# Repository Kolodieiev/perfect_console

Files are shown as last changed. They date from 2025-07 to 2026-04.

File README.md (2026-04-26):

Проєкт “Ідеальна консоль” це спроба створити універсальну електронну плату, для комфортного програмування на її основі різноманітних електронних пристроїв, таких як ігрові консолі, програвачі музики, пульти керування тощо.
Завдяки продуктивному мікроконтролеру ESP32S3 N16R8 плата може виконувати купу завдань та обчислень, а наявність 8 мб оперативної та 16 мб постійної пам'яті, забезпечує достатньо місця для реалізації досить об’ємних проєктів прошивок, в тому числі з використанням графіки. 

<br>

#### Прошивка
В репозиторії, крім файлів проєкту електронної плати, містяться повністю відкриті базові прошивки, написані мовою C++, для обох мікроконтролерів. Прошивка для ESP32S3 базується на основі фреймворку Pixeler, та містить багато прикладів побудови графічного інтерфейсу різної складності. 
До їх списку входять різні види меню, графічний інтерфейс для сканування та підключення до WiFi точки доступу, файловий менеджер, mp3-плеєр, вікна з різними видами налаштувань, приклади 2D-ігор на кастомному ігровому рушії та інші.

Скриншоти з прошивки:<br>
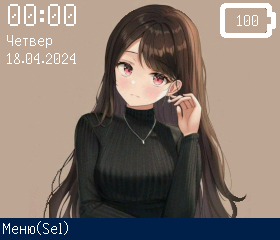
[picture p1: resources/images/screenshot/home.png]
main_context

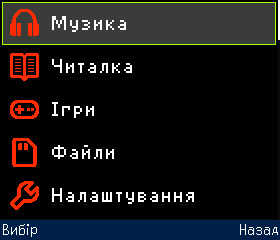
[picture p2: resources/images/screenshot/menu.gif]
menu_context
<br>
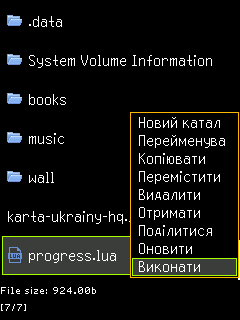
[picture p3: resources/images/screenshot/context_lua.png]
file_manager

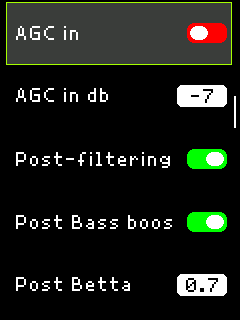
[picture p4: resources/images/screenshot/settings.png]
settings_context

<br>
Демонстрація можливостей ігрового рушія(зібрано в портованій версії для ПК):
<br>
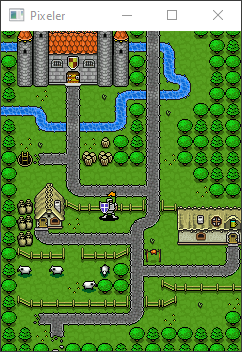
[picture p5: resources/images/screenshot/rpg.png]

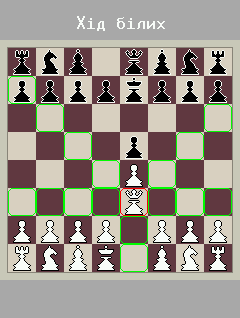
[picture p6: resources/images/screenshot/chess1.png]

<br>
Більше скриншотів можна знайти в [Screenshots](resources/images/screenshot)
<br>

#### Для кого
Проєкт розрахований на користувачів, які хочуть навчитися виготовляти або замовляти виготовлення електронних плат, збирати їх по схемі та програмувати мікроконтролери. Також він підійде досвідченим розробникам, яким просто цікаво програмувати залізо у вільний час та вивчати щось нове для себе. 
Для збірки проєкту необхідно мати досвід пайки середнього або вище рівня та відповідні інструменти.

<br>

#### Модульність
Головна особливість плати полягає в тому, що користувач може самостійно обрати, який модуль йому використовувати для своїх задач. На платі передбачено місця тільки для основних компонентів, або таких, які складно закріпити в корпусі окремо, все інше необхідно самостійно обирати з огляду на власні потреби та можливості.
<br>
<br>
[Фото зібраних плат](resources/images/pcb)

<br>

#### Корпус
Розробка корпусу для виготовлення на 3D-принтері не планується в межах даного проєкту. Користувач повинен самостійно спроектувати корпус для свого пристрою в залежності від використаних модулів. 

<br>

#### Мікроконтролер
Для забезпечення функціонування плати використовується два мікроконтролера - далі МК, ESP32S3 та CH32V006E8R6. Ці МК обрано через дуже хороше співвідношення ціна/можливості та значну кількість GPIO. Очікується, що перший МК буде мозком пристрою, який виконуватиме основну прошивку, а другий - допоміжний, що виконуватиме роль мікросхеми розширення, завдяки якій вивільняються 11 пінів основного МК. Мікроконтролери можуть спілкуватися один з одним по шині I2C. Для підтримки рівноправного двостороннього зв'язку додано окрему лінію між МК, яка може бути використана для генерації переривань.

<br>

#### GPIO
До однієї з двох шин SPI на ESP32 приєднано роз’єм карти пам’яті MicroSD. Усі інші незадіяні виводи цього МК виведено на штирьові роз’єми та контактні площадки. Усього доступно вільних пінів 19 + шина I2C + UART. Усі вільні виводи ESP32 згруповано на штирьових роз’ємах таким чином, щоб до них можна було підключити з допомогою шлейфів будь-який популярний SPI-дисплей, модуль звуку, який керується по I2S протоколу, цифровий мікрофон та UART-версію модулів LoRa. До кожної групи роз’ємів додано піни живлення, які вмикаються польовими транзисторами. В кастомній прошивці до цих роз’ємів можуть бути підключені будь-які інші модулі на розсуд користувача.

Частина виводів(п’ять) CH32 підключені до ключів керування живленням. Усі інші піни також виведені на штирьові роз’єми. У стандартній конфігурації до цих пінів очікується підключення кнопки живлення, кнопки PTT, ліній UART, програматора, та 8 кнопок керування, 6 з яких, можуть бути налаштовані як сенсорні. 

В будь-якій користувацькій конфігурації обов’язковою є тільки кнопка живлення. Усі інші вільні виводи мікроконтролерів можуть бути налаштовані, відповідно до їх документації, на інші задачі. Окрім того, за особливої необхідності, можуть бути звільнені додаткові 4 піна CH32, які підключені до затворів ключів живлення в кожній групі штирьових роз’ємів.

<br>

#### Живлення
Очікується, що плата “Ідеальної консолі” буде використовуватися саме в автономному варіанті з використанням високоємнісного акумулятора або збірки акумуляторів. Проте з деякими незначними модифікаціями можливе її використання виключно в стаціонарному варіанті, наприклад, для навчання або відлагодження. На платі передбачено місця для штирьових роз’ємів, до яких можна підключити будь-який USB роз’єм, та будь-який понижуючий DC-DC перетворювач. Також окремо виведено роз’єм з підсиленими доріжками для живлення зовнішніх пристроїв, як від DC-DC перетворювача, так і напряму від акумулятора. Для заряджання акумулятора використовується модуль TP4056 без захисту. Для нього передбачено окреме місце на платі для відводу тепла. Плату або плати захисту від перерозряду пропонується встановлювати окремо на акумулятор в залежності від того, які значення струму планується знімати з нього. Якщо очікується загальне споживання струму понад 1А, дуже рекомендується припаювання проводів до плати, замість використання штирьових роз’ємів в схемі живлення.

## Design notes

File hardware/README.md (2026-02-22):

##### Загальні рекомендації

* Не запаюйте акумулятор та DC-DC перетворювач безпосередньо до плати, поки не завантажите прошивку на CH32V006E8R6.
* Не приєднуйте жоден із модулів, таких як дисплей, до плати та не вставляйте карту пам'яті в роз'єм, доки не переконаєтесь, що на платі відсутні КЗ, а обидва мікроконтролери успішно прошиті.
* Мікроконтролер CH32V006E8R6 не може бути замінений на будь-яку інший з серії через невідповідність пінів.
* Модуль ESP32-S3 не може бути замінений на звичайний ESP32 чи S2 чи будь-який інший через невідповідність пінів та підтримку можливостей.
* Шлейф дисплею мусить бути якомога коротшим, настільки дозволяють вимоги корпусу. 
* Резистори підтяжки ліній MISO/MOSI/CLK карти пам'яті можуть мати значення 10-22к. 
* Резистори підтяжки затворів мосфетів можуть мати значення 30к-50к.
* Резистори обмеження струму на затвори мосфетів можуть мати значення 10-30ом.
* Конденсатори 10мкф можуть бути замінені на low-esr електролітичні або танталові, але з урахуванням полярності.
* DC-DC перетворювач може бути використаний будь-який на 3.3В 1.5А+. Рекомендованими є XL63070/TPS63070/mini-560 3.3v.
* Захист акумулятора від перерозряду, КЗ та високих струмів необхідно купити окремо з розрахунку 1 модуль на 2А потенційного струму.
* Якщо планується використання підсилювача звуку або модуля LoRa, рекомендуються купувати високострумний акумулятор та з'єднати паралельно два модуля захисту.
* Під модуль TP4056 рекомендується розмістити термопрокладку для відводу тепла на плату.
* Для комфортного використання плати рекомендується купувати акумулятор з ємністю від 1000маг. Бажано 2-3к, якщо планується використання WiFi. Найкраще для цієї задачі підходять високострумні 18650 або 21700 зі встановленими самостійно модулями захисту.
* Під модуль ESP32-S3 бажано нанести маленьку каплю процесорної термопасти і міцно притиснути модуль до плати, якщо паста густа, можна легко порухати модуль в різні сторони, для кращого розмазування термопасти. 
* Запаювати площадку знизу не обов'язково і не рекомендуються новачкам.
* Дисплей може бути використаний будь-який SPI, але основна прошивка буде розроблюватися тільки для дисплеїв на драйвері ST7789.
* Модуль мікрофона, якщо планується його використання, може бути замінений на будь-який інший сумісний з INMP441.
* Модуль LoRa може бути використаний серії E32 або E220 з UART на 400-440мГц. Інші не тестувались та не мають бібліотек підтримки. 
* Усі модулі не є обов'язковими для функціонування плати, окрім модулів живлення, мікроконтролерів та їх обв'язки.

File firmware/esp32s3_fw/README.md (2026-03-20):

> [!WARNING]
> Прошивка збирається плагіном `Pioarduino` та не може бути зібрана за допомогою `Platformio`!

##### Інструкція з прошивки ESP32S3

* Перш ніж розпочинати прошивку ESP32S3, необхідно спершу прошити CH32V006E8R6. Без цього пункту нічого не вийде.
* Коли CH32 прошито, потрібно обов'язково підключити акумулятор та понижуючий DC-DC перетворювач на свої місця. Звіряйтесь зі схемою куди, що і якою сторною підключаєте, аби не пошкодити плату чи компоненти на ній.
* Коли акумулятор підключено, на контактах 4v2 та GND(поряд з 4v2) роз'єму PWR_OUT повинна бути напруга акумулятора. Якщо напруга відсутня, а на акумуляторі встановлено плату захисту, спробуйте підключити короткочасно плату консолі до зарядного пристрою. Після цього плата захисту повинна розблокуватися, а на вищезгаданих контактах з'явиться напруга.
Якщо цього не відбулося, знайдіть та приберіть КЗ на платі консолі та переконайтеся в якості пайки.
* Якщо напруга акумулятора наявна на платі консолі, натисніть та міцно утримуйте протягом 4 сек кнопку, яка підключена до контактів PWR_Btn, або замкніть на 4 сек ці контакти металевим пінцетом. 
* Заміряйте напругу на контактах 4V2 та нижньому GND, вона не повинна зникнути. А на контактах 3v3 та верхньому GND має з'явитися напруга 3.3В з DC-DC перетворювача.
Якщо напруга акумулятора зникла, шукайте КЗ на платі. Якщо напруга з DC-DC перетворювача не з'явилася, заміряйте напругу на затворі одного з транзисторів Q5/Q6 відносно нижнього GND на роз'ємі PWR_OUT. Там повинна бути напруга акумулятора. Якщо напруга відсутня, шукайте проблему в якості пайки CH32 або по шляху доріжки від транзистора до CH32. Краще всього для цього використовувати файли проєкту плати для Kicad.
* Якщо відповідні напруги наявні на контактах PWR_OUT. Підключіть плату консолі до ПК. Якщо драйвери встановлено коректно, у списку пристроїв повинен з'явитися USB JTAG/serial debug unit. Якщо пристрій автоматично підключається і відключається, натисніть кнопку Boot на платі консолі і не відпускаючи її короткочасно натисніть Reset на платі. Після цього можна відпустити Boot. Пристрій USB JTAG/serial debug unit повинен перестати автоматично перепідключатися.
* Відкрийте VS Code, встановіть до нього плагін Pioarduino. Зверніть увагу, плагін повинен називатися саме Pioarduino, а не Platformio. Другий плагін необхідно видалити та видалити папку .platformio, якщо його було встановлено раніше.
* Відкрийте папку проєкта таким чином, щоб цей файл README знаходився на найвищому рівні в списку проєкта. У Windows можна клікнути на порожнє місце поряд з цим файлом у файловому менеджері, та обрати пункт відкрити в VS Code. 
* Зберіть прошивку та завантажте її на МК через інтерфейс або кнопки на панелі навігації плагіна. Більш детальну інструкцію зі збірки проєкта можна знайти в мережі, якщо виникнуть додаткові питання.
* Якщо все пройшло успішно, можна підключати модулі дисплея, звукової карти тощо.

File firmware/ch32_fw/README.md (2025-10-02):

Прошивка допоміжного мікроконтролера CH32V006E8R6 в корпусі QSOP-24 для проєкту "Ідеальна консоль". 
Прошивка збирається в програмі MounRiver Studio 2 та заливається на МК з допомогою універсального, для мікроконтролерів WCH, програматора WCH-LinkE V2.
Важливо, програматор WCH-Link V1 не підходить для програмування CH32V006E8R6!

##### Підключення програматора

* Коли плату зібрано, необхідно від'єднати USB-живлення, акумулятор та, можливо, вхід DC-DC перетворювача. 
* Після цього потрібно підключити програматор до плати за наступною схемою:

5V програматора -> 4v2 на роз'ємі PWR_OUT.
GND програматора -> GND на роз'ємі PWR_OUT.
SWDIO програматора -> SWIO на роз'ємі CH_FLASH.
SWCLK програматора -> CH_RESET на роз'ємі CH_FLASH.

##### Налаштування проєкту

* Далі необхідно підключити програматор до ПК, на якому встановлено "MounRiver Studio 2".
* Після підключення програматора, в "MounRiver Studio 2" потрібно відкрити цей проєкт прошивки та перейти в меню "Flash -> Download Configuration".
* В розділі "General -> Target MCU Type" обрати "CH32V006 -> CH32V006E8R6".
* В розділі "Download -> Download Settings" натиснути кнопку "Query" навпроти поля "Debugger Target Mode". 
Повинне з'явитися повідомлення "Succeed", а в полі встановитися автоматично вибір "RISC-V". Якщо з'явилося повідомлення "WCH-Link not found" перевірте підключення програматора до ПК та наявність драйверів. На Windows драйвер встановлюється разом з "MounRiver Studio 2" автоматично. Якщо в полі вибору встановився "ARM", необхідно змінити режим на програматорі, як вказано в інструкції до нього.
* Далі в полі "Erase Code Flash" вручну обрати пункт "By Power Off" та натиснути "Applay" навпроти цього поля. Повинно з'явитися повідомлення "Clear CodeFlash... Succeed".
* Тепер, якщо натиснути кнопку "Query" навпроти поля "Linked MCU Type", в полі автоматично повинне встановитися значення "CH32V002/3/4/5/6/7".
* Після цього необхідно натиснути головну кнопку "Applay" вікна, для збереження налаштувань.

##### Збірка проєкту та прошивка мікроконтролера

* Після того, як закрилося вікно налаштувань, натисніть кнопку "Build Project".
* Після збірки проєкту натисніть кнопку "Download". У виводі повинні з'явитися повідомлення з етапами прошивки, останнє із яких - "Download Finished". Якщо отримано будь-яке інше повідомлення про помилку, переконайтеся у якості підключення програматора до плати, а також у якості пайки штирьових розємів та самого CH32V006E8R6.
* Тепер CH32V006E8R6 прошитий і готовий до використання. Від'єднайте програматор від плати після чого підключіть акумулятор та DC-DC.
* Після цього можна перейти до прошивки ESP32S3.

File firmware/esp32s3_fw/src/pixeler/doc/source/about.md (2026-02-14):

# Про проєкт

Pixeler це компроміс між зручним для використання, швидким та надійним кодом. Проте на першому місці все ж таки стоять зручність та швидкодія.

Для кращого розуміння, принципів функціонування фреймоврку варто ознайомитися з наступними підходами до його розробки:
* Ми дуже не любимо послідовності викликів C-шних функцій, тому загортаємо все в зручні класи.
Окрім коду де потрібна максимальна продуктивність. В таких випадках можна й регістр читати.
* Замість копіювання даних або об'єктів, ми користуємося сирими вказівниками та посиланнями, окрім випадків коли потрібна саме копія.
* Ми завжди хочемо перевикористовувати великі масиви даних, такі як зображення. Тому об'єкт не видаляє дані за отриманим вказівником, якщо ці дані потенційно займають багато місця в пам'яті та можуть бути перевикористані іншим об'єктом.
* В той же час ми не хочемо кешувати вказівники на всі створені невеликі об'єкти. Тому якщо об'єкт, що приймає вказівник, є контейнером для цих вказівників, він повинен самостійно викликати видалення за цими вказівниками, навіть, якщо не він їх створював.
* Ми не бачимо нічого поганого в тому, щоб отримувати доступ до "популярного" об'єкта по закешованому вказівнику, навіть, якщо цей об'єкт видаляється в іншому місці. Але лише за умови, що використовується машина станів, яка гарантовано унеможливить звертання до висячого вказівника.
* Виклик віртуальних методів кращий за шаблони.
* Якщо отримали помилку або неочікуване значення в коді, викликаємо перевантаження прошивки, аби розробник звернув увагу на цю проблему під час тестування.
Але це не стосується обробки зовнішніх вхідних даних.
* За бажання, необережними програмуванням можна зламати майже будь-яку систему. 
Тому перевіряємо тільки зовнішні вхідні дані, вказівники на nullptr та значення, які програміст вводить дуже часто через що може випадково помилитися.
В інших випадках очікуємо, що дані валідні, аби не роздувати прошивку перевірками заради перевірок. Тому якщо, наприклад, метод повинен отримувати ціле число в позитивному діапазоні, параметр методу краще оголосити беззнаковим, а відповідальність за вхідне значення перекласти на розробника, аніж додавати перевірку знака, яка можливо ніколи і не знадобиться.

Не дивлячись на те, що майже всі ці підходи порушують загальноприйняті принципи класичного програмування, їх було обрано з певних, цілком об'єктвиних для програмування мікроконтролерів, причин.<br>
Ви можете лише прийняти їх або відмовитися від використання Pixeler, якщо вважаєте такий підхід до програмування недостатньо надійним для вашої задачі.

Розробка проєкту виконується на ОС Linux та періодично тестується на Windows, тому деякі інструменти збірки можуть бути налаштовані некоректно на інших системах окрім Linux в певний момент.<br>
Для тестування прошивки використовується мікроконтролер ESP32S3, на ESP32 та ESP32P4 код тестується періодично, 
тому деякий функціонал може працювати некоректно в певний момент. Або може працювати дещо інакше, через внутрішні відмінності цих мікроконтролерів.

## Про документацію

Ця документація створена з метою навчити створювати прошивки для ESP на Pixeler будь-кого, в тому числі новачків.
Вона не містить повного переліку та опису усіх методів в класах. З ним користувач повинен самостійно ознайомитись у відповідних файлах.
Усі неочевидні моменти архітектури Pixeler, будуть описані в ній. Проте користувач повинен самостійно розібратися з усіма, незрозумілими для нього, речами в мовах C++/Lua за допомогою ШІ або пошукових систем.

## Скорочення та визначення

МК - Мікроконтролер.<br>
ESP - Мікроконтролер серії ESP32/ESP32S3/ESP32P4.
GUI - Графічний інтерфейс користувача.

## Правила іменування

В Pixeler використовуються наступні правила іменування.

* Префікс `I` в імені типу означає, що клас є абстрактним. Наприклад, `IWidget`.
* Префікс `__`(два нижніх підкреслення) в імені методу означає, що метод не рекомендується або заборонено до виклику користувачем. Наприклад, `void __tick();`
* Префікс `_`(одне нижнє підкреслення) в імені об'єкта означає, що він є глобальним. Наприклад, `_fs`.
* Усі букви в верхньому регістрі означають ім'я визначення або константного значення. Наприклад, `SOME_NAME`.
* Для іменування типів використовується `UpperCamelCase`.
* Для іменування методів використовується `lowerCamelCase`.
* Для іменування об'єктів використовується `snake_case`.

## Повідомити про помилку

<a href="https://github.com/Kolodieiev/perfect_console/issues/new" target="_blank">Створити issue на Github</a>

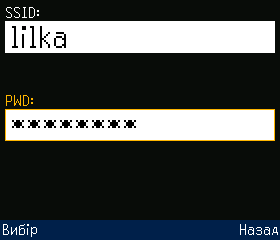
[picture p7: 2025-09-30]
resources/images/screenshot/textbox.png

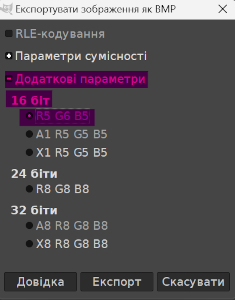
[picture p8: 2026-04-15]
firmware/esp32s3_fw/src/pixeler/doc/source/img/img_convert/gimp_bmp_convert.png

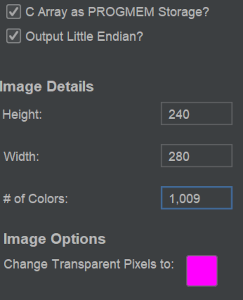
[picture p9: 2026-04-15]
firmware/esp32s3_fw/src/pixeler/doc/source/img/img_convert/GUIslice_Image2C.png

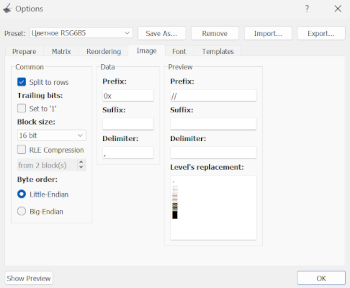
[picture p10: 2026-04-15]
firmware/esp32s3_fw/src/pixeler/doc/source/img/img_convert/LCD_img_converter_2.png

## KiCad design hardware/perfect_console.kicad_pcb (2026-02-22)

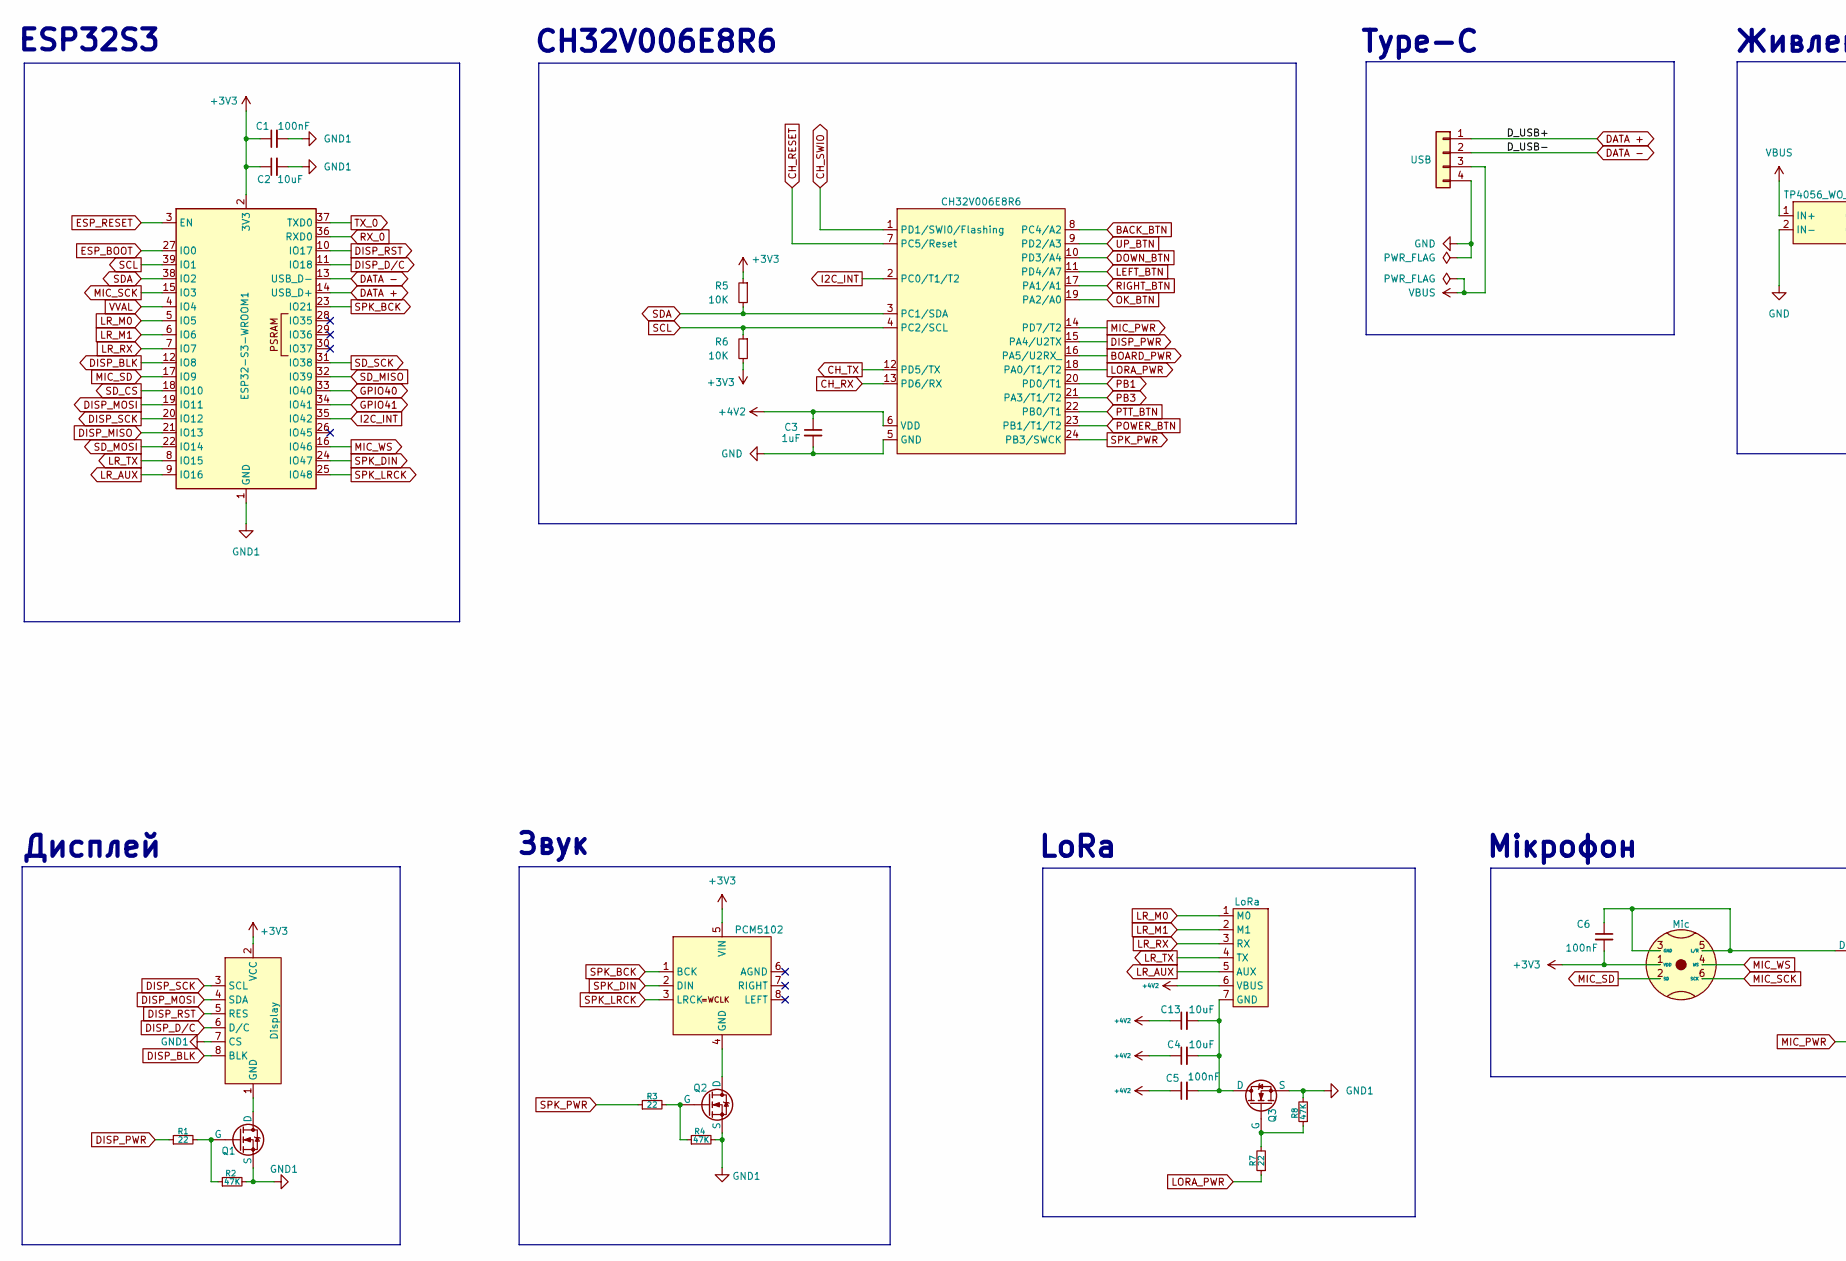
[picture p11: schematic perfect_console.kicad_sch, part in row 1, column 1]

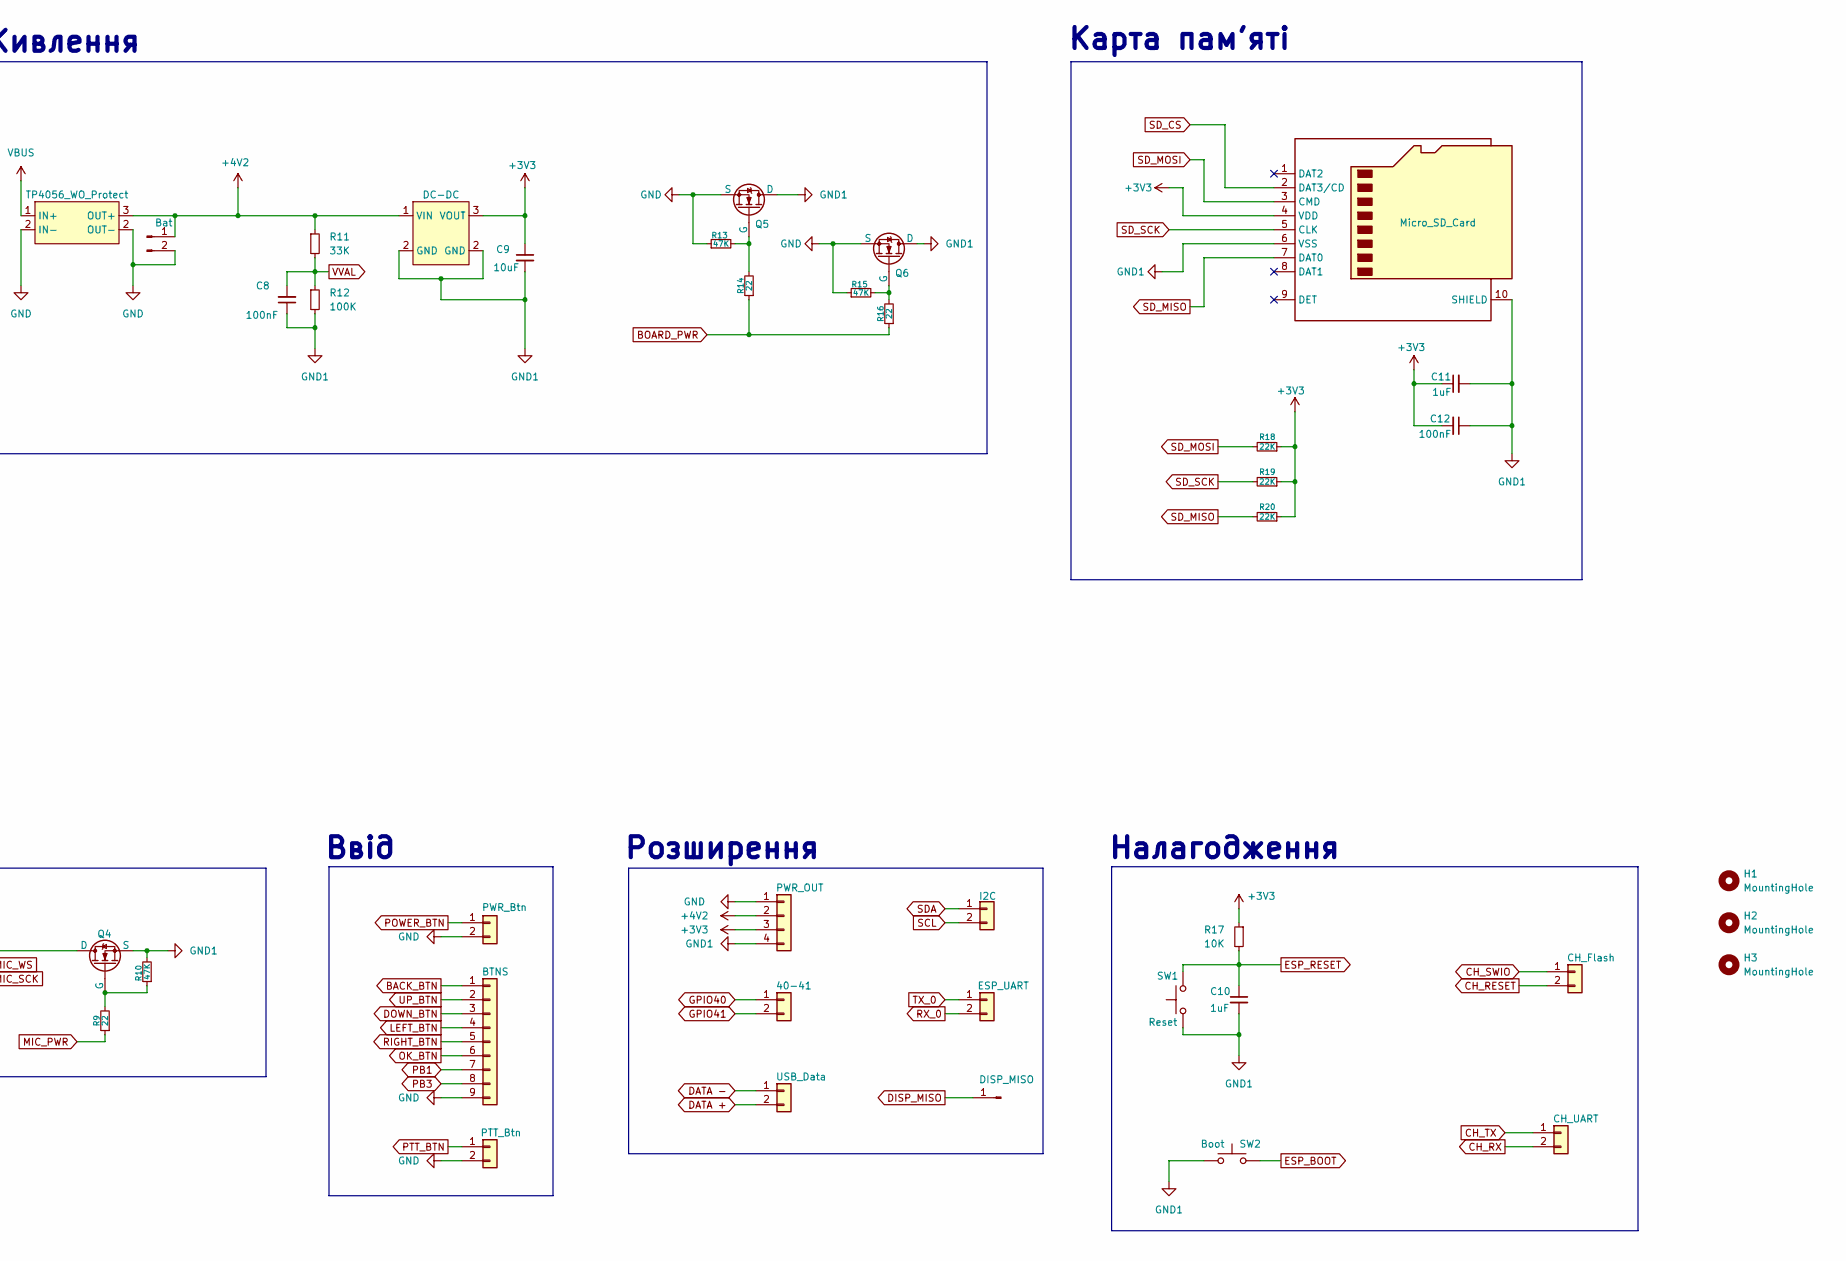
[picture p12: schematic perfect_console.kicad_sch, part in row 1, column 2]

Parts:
C1, C5, C6, C8, C12: 100nF; C_1206_3216Metric_Pad1.33x1.80mm_HandSolder
C2, C4, C9, C13: 10uF; C_1206_3216Metric_Pad1.33x1.80mm_HandSolder
C3, C10, C11: 1uF; C_1206_3216Metric_Pad1.33x1.80mm_HandSolder
H1, H2, H3: MountingHole; MountingHole_2.7mm_M2.5_DIN965_Pad
J1: USB; PinHeader_1x04_P2.54mm_Vertical
J2: TP4056_WO_Protect; Charge_Controller_TP4056_WO_Protect
J3: Bat; PinHeader_1x02_P2.54mm_Vertical
J4: PWR_Btn; PinHeader_1x02_P2.54mm_Vertical
J5: BTNS; PinHeader_1x09_P2.54mm_Vertical
J6: PTT_Btn; PinHeader_1x02_P2.54mm_Vertical
J7: PWR_OUT; PinHeader_1x04_P2.54mm_Vertical
J8: 40-41; PinHeader_1x02_P2.54mm_Vertical
J9: USB_Data; PinHeader_1x02_P2.54mm_Vertical
J10: I2C; PinHeader_1x02_P2.54mm_Vertical
J11: ESP_UART; PinHeader_1x02_P2.54mm_Vertical
J12: CH_UART; PinHeader_1x02_P2.54mm_Vertical
J13: CH_Flash; PinHeader_1x02_P2.54mm_Vertical
J14: Micro_SD_Card; J_SD_Card-micro_socket_A
J16: DISP_MISO; TestPoint_Pad_1.5x1.5mm
Q1, Q2, Q3, Q4, Q5, Q6: A09T; SOT-23
R1, R3, R7, R9, R14, R16: 22; R_1206_3216Metric_Pad1.30x1.75mm_HandSolder
R2, R4, R8, R10, R13, R15: 47K; R_1206_3216Metric_Pad1.30x1.75mm_HandSolder
R5, R6, R17: 10K; R_1206_3216Metric_Pad1.30x1.75mm_HandSolder
R11: 33K; R_1206_3216Metric_Pad1.30x1.75mm_HandSolder
R12: 100K; R_1206_3216Metric_Pad1.30x1.75mm_HandSolder
R18, R19, R20: 22K; R_1206_3216Metric_Pad1.30x1.75mm_HandSolder
SW1: Reset; SW_PUSH_6mm
SW2: Boot; SW_PUSH_6mm
U1: ESP32-S3-WROOM1; ESP32-S3-WROOM-1
U2: Display; PinHeader_1x08_P2.54mm_Vertical
U3: PCM5102; PinHeader_1x05_P2.54mm_Vertical
U4: CH32V006E8R6; Allegro_QSOP-24_3.9x8.7mm_P0.635mm
U5: LoRa; PinHeader_1x07_P2.54mm_Vertical
U7: Mic; PinHeader_2x03_P2.54mm_Vertical
U8: DC-DC; PinHeader_2x02_P2.54mm_Vertical

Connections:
+3V3: C1.1, C2.1, C6.2, C9.1, C11.1, C12.2, J7.3, J14.4 (VDD), R5.1, R6.2, R17.1, R18.1, R19.1, R20.1, U1.2 (3V3), U2.2 (VCC), U3.5 (VIN), U7.1 (VDD), U8.3 (VOUT)
+4V2: C3.1, C4.1, C5.1, C13.1, J2.3 (OUT+), J3.1, J7.2, R11.1, U4.6 (VDD), U5.6 (VBUS), U8.1 (VIN)
BACK_BTN: J5.1, U4.8 (PC4/A2)
BOARD_PWR: R14.1, R16.1, U4.16 (PA5/U2RX_)
CH_RESET: J13.2, U4.7 (PC5/Reset)
CH_RX: J12.2, U4.13 (PD6/RX)
CH_SWIO: J13.1, U4.1 (PD1/SWI0/Flashing)
CH_TX: J12.1, U4.12 (PD5/TX)
DATA +: J1.1, J9.2, U1.14 (USB_D+)
DATA -: J1.2, J9.1, U1.13 (USB_D-)
DISP_BLK: U1.12 (IO8), U2.8 (BLK)
DISP_D/C: U1.11 (IO18), U2.6 (D/C)
DISP_MISO: J16.1, U1.21 (IO13)
DISP_MOSI: U1.19 (IO11), U2.4 (SDA)
DISP_PWR: R1.1, U4.15 (PA4/U2TX)
DISP_RST: U1.10 (IO17), U2.5 (RES)
DISP_SCK: U1.20 (IO12), U2.3 (SCL)
DOWN_BTN: J5.3, U4.10 (PD3/A4)
ESP_BOOT: SW2.2, U1.27 (IO0)
ESP_RESET: C10.1, R17.2, SW1.2, U1.3 (EN)
GND: C3.2, J1.4, J2.2 (IN-), J3.2, J4.2, J5.9, J6.2, J7.1, Q5.2 (S), Q6.2 (S), R13.1, R15.1, U4.5 (GND)
GND1: C1.2, C2.2, C8.1, C9.2, C10.2, C11.2, C12.1, J7.4, J14.6 (VSS), J14.10 (SHIELD), Q1.2 (S), Q2.2 (S), Q3.2 (S), Q4.2 (S), Q5.3 (D), Q6.3 (D), R2.2, R4.2, R8.2, R10.2, R12.2, SW1.1, SW2.1, U1.1 (GND), U1.40 (GND), U1.41 (GND), U2.7 (CS), U8.2 (GND)
GPIO40: J8.1, U1.33 (IO40)
GPIO41: J8.2, U1.34 (IO41)
I2C_INT: U1.35 (IO42), U4.2 (PC0/T1/T2)
LEFT_BTN: J5.4, U4.11 (PD4/A7)
LORA_PWR: R7.1, U4.18 (PA0/T1/T2)
LR_AUX: U1.9 (IO16), U5.5 (AUX)
LR_M0: U1.5 (IO5), U5.1 (M0)
LR_M1: U1.6 (IO6), U5.2 (M1)
LR_RX: U1.7 (IO7), U5.3 (RX)
LR_TX: U1.8 (IO15), U5.4 (TX)
MIC_PWR: R9.1, U4.14 (PD7/T2)
MIC_SCK: U1.15 (IO3), U7.6 (SCK)
MIC_SD: U1.17 (IO9), U7.2 (SD)
MIC_WS: U1.16 (IO46), U7.4 (WS)
unnamed: Q1.3 (D), U2.1 (GND)
unnamed: Q1.1 (G), R1.2, R2.1
unnamed: Q2.3 (D), U3.4 (GND)
unnamed: Q2.1 (G), R3.2, R4.1
unnamed: C4.2, C5.2, C13.2, Q3.3 (D), U5.7 (GND)
unnamed: Q3.1 (G), R7.2, R8.1
unnamed: C6.1, Q4.3 (D), U7.3 (GND), U7.5 (L/R)
unnamed: Q4.1 (G), R9.2, R10.1
unnamed: Q5.1 (G), R13.2, R14.2
unnamed: Q6.1 (G), R15.2, R16.2
OK_BTN: J5.6, U4.19 (PA2/A0)
PB1: J5.7, U4.20 (PD0/T1)
PB3: J5.8, U4.21 (PA3/T1/T2)
POWER_BTN: J4.1, U4.23 (PB1/T1/T2)
PTT_BTN: J6.1, U4.22 (PB0/T1)
RIGHT_BTN: J5.5, U4.17 (PA1/A1)
RX_0: J11.2, U1.36 (RXD0)
SCL: J10.2, R6.1, U1.39 (IO1), U4.4 (PC2/SCL)
SDA: J10.1, R5.2, U1.38 (IO2), U4.3 (PC1/SDA)
SD_CS: J14.2 (DAT3/CD), U1.18 (IO10)
SD_MISO: J14.7 (DAT0), R20.2, U1.32 (IO39)
SD_MOSI: J14.3 (CMD), R18.2, U1.22 (IO14)
SD_SCK: J14.5 (CLK), R19.2, U1.31 (IO38)
SPK_BCK: U1.23 (IO21), U3.1 (BCK)
SPK_DIN: U1.24 (IO47), U3.2 (DIN)
SPK_LRCK: U1.25 (IO48), U3.3 (LRCK)
SPK_PWR: R3.1, U4.24 (PB3/SWCK)
TX_0: J11.1, U1.37 (TXD0)
UP_BTN: J5.2, U4.9 (PD2/A3)
VBUS: J1.3, J2.1 (IN+)
VVAL: C8.2, R11.2, R12.1, U1.4 (IO4)

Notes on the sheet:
Розширення
Карта пам'яті
Налагодження
Дисплей
CH32V006E8R6
Живлення
Звук
Type-C
ESP32S3
Ввід
LoRa
Мікрофон

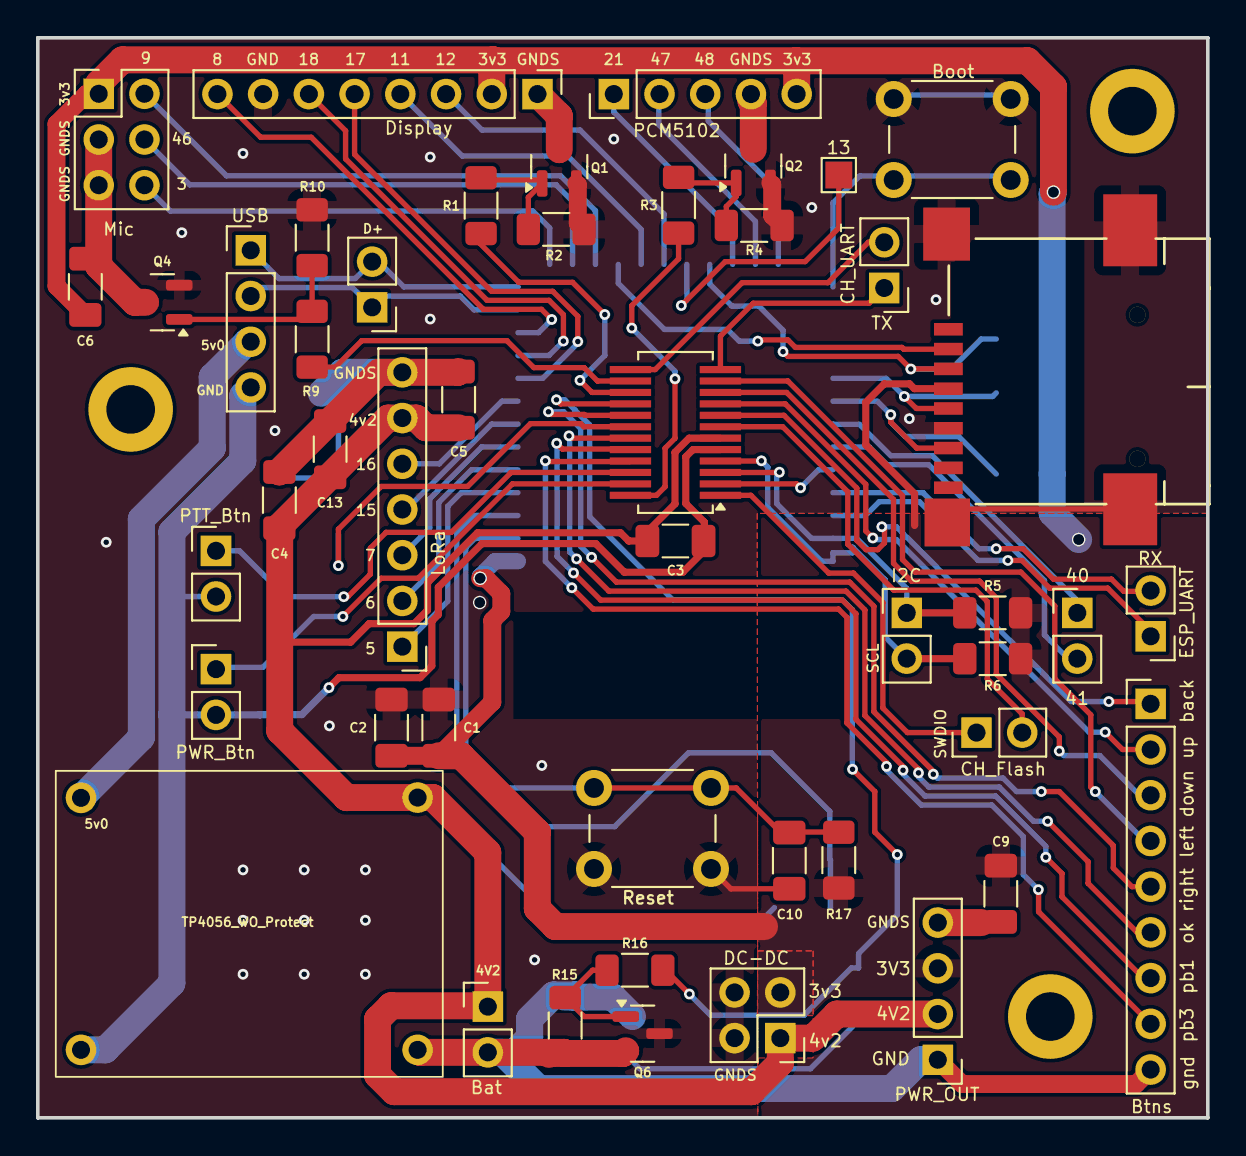
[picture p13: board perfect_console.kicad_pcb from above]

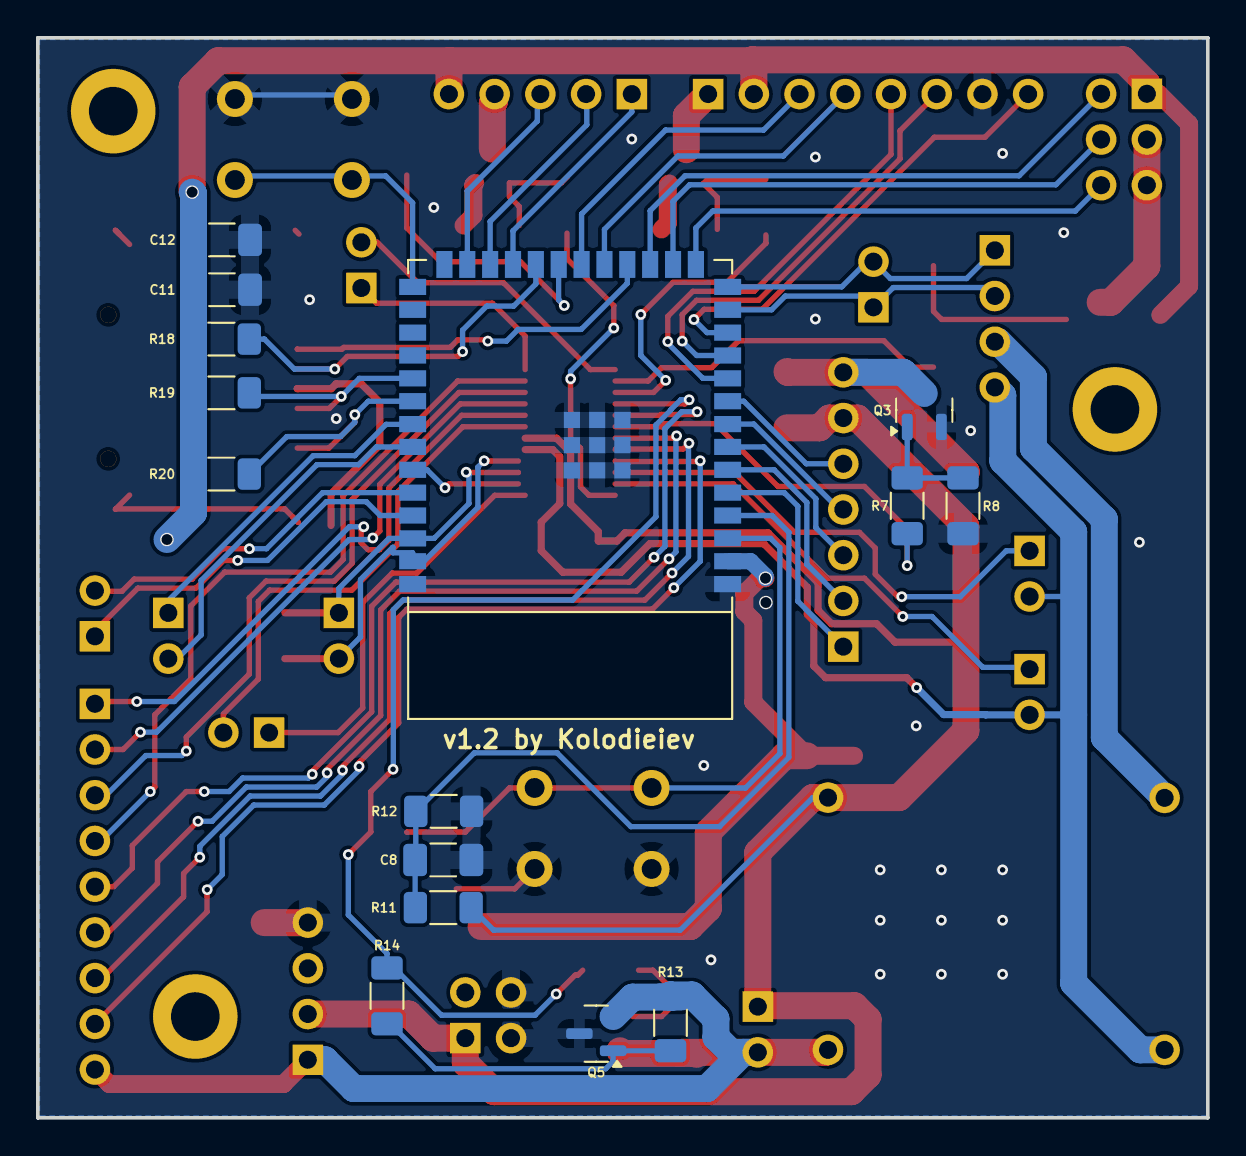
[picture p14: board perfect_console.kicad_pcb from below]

Board: 2 copper layers, 65.0 x 60.0 mm, 65 parts (15 on the bottom side), 67 nets.

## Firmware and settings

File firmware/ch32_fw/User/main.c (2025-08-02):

#include <debug.h>
#include <gpio.h>
#include <i2c_slave.h>
#include "input.h"
#include "touch.h"
#include "CoprocessorCMD.h"

// #define DEBUG_LOG

//------------------------------------------------------------------------------------------------------------- btns
#define BTNS_NUM 7

#define PIN_POWER_BTN 23

#define PIN_PTT_BTN 22
#define PIN_OK_BTN 19
#define PIN_BACK_BTN 8
#define PIN_LEFT_BTN 11
#define PIN_RIGHT_BTN 17
#define PIN_UP_BTN 9
#define PIN_DOWN_BTN 10

#define PIN_PB1 20
#define PIN_PB3 21

#define INPUT_UPD_TIME_MS 10

//------------------------------------------------------------------------------------------------------------- keys
#define PIN_MIC_KEY 14
#define PIN_DISPLAY_KEY 15
#define PIN_POWER_KEY 16
#define PIN_LORA_KEY 18
#define PIN_AUDIO_OUT_KEY 24

#define PIN_I2C_INT 2

//------------------------------------------------------------------------------------------------------------- i2c

#define BTNS_NUM_BUFF_SIZE ((BTNS_NUM + 7) / 8)
#define I2C_TEMP_BUFF_SIZE 5

#define I2C_FREQ 100000
#define RX_ADDR 0x66

//

volatile uint8_t _data_size_to_send = 0;
uint8_t _i2c_out_buff[I2C_TEMP_BUFF_SIZE] = {0};
uint8_t _btns_state_buff[BTNS_NUM_BUFF_SIZE] = {0};

//------------------------------------------------------------------------------------------------------------- power
#define TIME_TO_TOGGLE_PWR 3000
uint8_t _is_sleeping = 0;

//------------------------------------------------------------------------------------------------------------- func
void initPins (void);
void deinitPins (void);

void initPwrBtnExti (void);
void deinitPwrBtnExti (void);

void goToSleep (void);
void wakeUp (void);
void EXTI7_0_IRQHandler (void) __attribute__ ((interrupt ("WCH-Interrupt-fast")));

void i2c_read_handler (const uint8_t *in_buff, uint8_t in_buff_size);
void i2c_write_handler (uint8_t *out_buff, volatile uint8_t *out_buff_size);

int main (void) {
    NVIC_PriorityGroupConfig (NVIC_PriorityGroup_1);
    SystemCoreClockUpdate();
    initMillis();
    initUsartPrintf (230400);

    //-----------------------

#ifdef DEBUG_LOG
    printf ("Begin...\r\n");
#endif

    pinMode (PIN_POWER_BTN, GPIO_Mode_IPU);
    initPins();
    enableI2CSlave (I2C_FREQ, RX_ADDR, i2c_read_handler, i2c_write_handler);
    goToSleep();

    unsigned long power_btn_press_time = 0;

    while (1) {
        if (_is_sleeping == 1) {
            if (digitalRead (PIN_POWER_BTN) == HIGH) {
                power_btn_press_time = 0;
#ifdef DEBUG_LOG
                printf ("PIN_POWER_BTN == HIGH\r\n");
#endif
                goToSleep();
            } else {
                if (power_btn_press_time == 0) {
                    power_btn_press_time = millis();
                } else if (millis() - power_btn_press_time > TIME_TO_TOGGLE_PWR) {
                    power_btn_press_time = 0;
                    wakeUp();
                }
            }

            continue;
        }

        if (digitalRead (PIN_POWER_BTN) == LOW) {
            if (power_btn_press_time == 0) {
                power_btn_press_time = millis();
            } else if (millis() - power_btn_press_time > TIME_TO_TOGGLE_PWR) {
                power_btn_press_time = 0;
                goToSleep();
            }

            continue;
        } else {
            power_btn_press_time = 0;
        }

        static unsigned long input_update_time = 0;
        if (millis() - input_update_time > INPUT_UPD_TIME_MS) {
            inputUpdate();
            loadInputState (_btns_state_buff);
            input_update_time = millis();
        }
    }
}

void initPins (void) {
#ifdef DEBUG_LOG
    printf ("initPins\r\n");
#endif

    pinMode (PIN_POWER_KEY, GPIO_Mode_Out_PP);
    digitalWrite (PIN_POWER_KEY, HIGH);

    pinMode (PIN_DISPLAY_KEY, GPIO_Mode_Out_PP);
    digitalWrite (PIN_DISPLAY_KEY, LOW);

    pinMode (PIN_AUDIO_OUT_KEY, GPIO_Mode_Out_PP);
    digitalWrite (PIN_AUDIO_OUT_KEY, LOW);

    pinMode (PIN_MIC_KEY, GPIO_Mode_Out_PP);
    digitalWrite (PIN_MIC_KEY, LOW);

    pinMode (PIN_LORA_KEY, GPIO_Mode_Out_PP);
    digitalWrite (PIN_LORA_KEY, LOW);

    enableInput (BTNS_NUM);

    addInputBtn (PIN_PTT_BTN);
    addInputBtn (PIN_OK_BTN);
    addInputBtn (PIN_BACK_BTN);
    addInputBtn (PIN_LEFT_BTN);
    addInputBtn (PIN_RIGHT_BTN);
    addInputBtn (PIN_UP_BTN);
    addInputBtn (PIN_DOWN_BTN);

    // addInputTouchBtn (PIN_OK_BTN);
    // addInputTouchBtn (PIN_BACK_BTN);
    // addInputTouchBtn (PIN_LEFT_BTN);
    // addInputTouchBtn (PIN_RIGHT_BTN);
    // addInputTouchBtn (PIN_UP_BTN);
    // addInputTouchBtn (PIN_DOWN_BTN);
}

void deinitPins (void) {
#ifdef DEBUG_LOG
    printf ("deinitPins\r\n");
#endif

    disableInput();
    disableTouchCap();

    pinMode (PIN_MIC_KEY, GPIO_Mode_IN_FLOATING);
    pinMode (PIN_DISPLAY_KEY, GPIO_Mode_IN_FLOATING);
    pinMode (PIN_POWER_KEY, GPIO_Mode_IN_FLOATING);
    pinMode (PIN_LORA_KEY, GPIO_Mode_IN_FLOATING);
    pinMode (PIN_AUDIO_OUT_KEY, GPIO_Mode_IN_FLOATING);
    pinMode (PIN_PTT_BTN, GPIO_Mode_IN_FLOATING);
    pinMode (PIN_OK_BTN, GPIO_Mode_IN_FLOATING);
    pinMode (PIN_BACK_BTN, GPIO_Mode_IN_FLOATING);
    pinMode (PIN_LEFT_BTN, GPIO_Mode_IN_FLOATING);
    pinMode (PIN_RIGHT_BTN, GPIO_Mode_IN_FLOATING);
    pinMode (PIN_UP_BTN, GPIO_Mode_IN_FLOATING);
    pinMode (PIN_DOWN_BTN, GPIO_Mode_IN_FLOATING);
}

void initPwrBtnExti (void) {
    RCC_PB2PeriphClockCmd (RCC_PB2Periph_AFIO, ENABLE);

    EXTI_InitTypeDef EXTI_InitStructure = {0};
    GPIO_EXTILineConfig (GPIO_PortSourceGPIOB, GPIO_PinSource1);
    EXTI_InitStructure.EXTI_Line = EXTI_Line1;
    EXTI_InitStructure.EXTI_Mode = EXTI_Mode_Interrupt;
    EXTI_InitStructure.EXTI_Trigger = EXTI_Trigger_Falling;
    EXTI_InitStructure.EXTI_LineCmd = ENABLE;
    EXTI_Init (&EXTI_InitStructure);

    NVIC_InitTypeDef NVIC_InitStructure = {0};
    NVIC_InitStructure.NVIC_IRQChannel = EXTI7_0_IRQn;
    NVIC_InitStructure.NVIC_IRQChannelPreemptionPriority = 1;
    NVIC_InitStructure.NVIC_IRQChannelSubPriority = 1;
    NVIC_InitStructure.NVIC_IRQChannelCmd = ENABLE;
    NVIC_Init (&NVIC_InitStructure);
}

void deinitPwrBtnExti (void) {
    EXTI_DeInit();
    NVIC_DisableIRQ (EXTI7_0_IRQn);
    RCC_PB2PeriphClockCmd (RCC_PB2Periph_AFIO, DISABLE);
}

void goToSleep (void) {
#ifdef DEBUG_LOG
    printf ("goToSleep\r\n");
#endif

    _is_sleeping = 1;
    initPwrBtnExti();
    deinitPins();
    PWR_EnterSTANDBYMode (PWR_STANDBYEntry_WFE);
}

void wakeUp (void) {
#ifdef DEBUG_LOG
    printf ("wakeUp\r\n");
#endif
    deinitPwrBtnExti();
    _is_sleeping = 0;
    initPins();
}

void EXTI7_0_IRQHandler (void) {
    if (EXTI_GetITStatus (EXTI_Line1) != RESET) {
#ifdef DEBUG_LOG
        printf ("EXTI\r\n");
#endif
        EXTI_ClearITPendingBit (EXTI_Line1);
    }
}

void i2c_read_handler (const uint8_t *in_buff, uint8_t in_buff_size) {
    CoprocessorCMD_t cmd = in_buff[0];
    switch (cmd) {
    case CCPU_CMD_GET_BTNS_STATE:
        memcpy (_i2c_out_buff, _btns_state_buff, BTNS_NUM_BUFF_SIZE);
        _data_size_to_send = BTNS_NUM_BUFF_SIZE;
        break;
    case CCPU_CMD_PIN_ON:
        if (in_buff_size < 2)
            return;
        digitalWrite (in_buff[1], HIGH);
        break;
    case CCPU_CMD_PIN_OFF:
        if (in_buff_size < 2)
            return;
        digitalWrite (in_buff[1], LOW);
        break;
    case CCPU_CMD_BTN_OFF:
        if (in_buff_size < 2)
            return;
        disableBtnByPos (in_buff[1]);
        break;
    case CCPU_CMD_BTN_ON:
        if (in_buff_size < 2)
            return;
        enableBtnByPos (in_buff[1]);
        break;
    case CCPU_CMD_DISABLE:
    case CCPU_CMD_ENABLE:
    default:
        return;
    }
}

void i2c_write_handler (uint8_t *out_buff, volatile uint8_t *out_buff_size) {
    *out_buff_size = _data_size_to_send;
    memcpy (out_buff, _i2c_out_buff, _data_size_to_send);
    for (uint32_t i = 0; i < _data_size_to_send; ++i)
        _i2c_out_buff[i] = 0;

    _data_size_to_send = 0;
}

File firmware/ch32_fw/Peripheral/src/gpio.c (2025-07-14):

#include "gpio.h"

typedef struct {
    GPIO_TypeDef *port;
    uint16_t pin;
    uint8_t adc_chann;
} PinMapping;

// CH32V006E8R6
const PinMapping _pin_map[] = {
    {GPIOD, GPIO_Pin_1,      ADC_CHANN_NONE}, // 1
    {GPIOC, GPIO_Pin_0,      ADC_CHANN_NONE}, // 2
    {GPIOC, GPIO_Pin_1,      ADC_CHANN_NONE}, // 3
    {GPIOC, GPIO_Pin_2,      ADC_CHANN_NONE}, // 4
    {NULL,  INVALID_MAPPING, ADC_CHANN_NONE}, // 5 GND
    {NULL,  INVALID_MAPPING, ADC_CHANN_NONE}, // 6 VCC
    {GPIOC, GPIO_Pin_5,      ADC_CHANN_NONE}, // 7
    {GPIOC, GPIO_Pin_4,      2             }, // 8
    {GPIOD, GPIO_Pin_2,      3             }, // 9
    {GPIOD, GPIO_Pin_3,      4             }, // 10
    {GPIOD, GPIO_Pin_4,      7             }, // 11
    {GPIOD, GPIO_Pin_5,      5             }, // 12 // TX
    {GPIOD, GPIO_Pin_6,      6             }, // 13 // RX
    {GPIOD, GPIO_Pin_7,      ADC_CHANN_NONE}, // 14
    {GPIOA, GPIO_Pin_4,      ADC_CHANN_NONE}, // 15
    {GPIOA, GPIO_Pin_5,      ADC_CHANN_NONE}, // 16
    {GPIOA, GPIO_Pin_1,      1             }, // 17
    {GPIOA, GPIO_Pin_0,      ADC_CHANN_NONE}, // 18
    {GPIOA, GPIO_Pin_2,      0             }, // 19
    {GPIOD, GPIO_Pin_0,      ADC_CHANN_NONE}, // 20
    {GPIOA, GPIO_Pin_3,      ADC_CHANN_NONE}, // 21
    {GPIOB, GPIO_Pin_0,      ADC_CHANN_NONE}, // 22
    {GPIOB, GPIO_Pin_1,      ADC_CHANN_NONE}, // 23
    {GPIOB, GPIO_Pin_3,      ADC_CHANN_NONE}, // 24
};

uint32_t portToMask (GPIO_TypeDef *port) {
    if (port == GPIOA)
        return RCC_PB2Periph_GPIOA;
    if (port == GPIOB)
        return RCC_PB2Periph_GPIOB;
    if (port == GPIOC)
        return RCC_PB2Periph_GPIOC;
    if (port == GPIOD)
        return RCC_PB2Periph_GPIOD;
    else {
        printf ("\nError: Unknown gpio port");
        return 0;
    }
}

void disablePort (GPIO_TypeDef *port) {
    if (!isPortEnabled (port))
        return;

    GPIO_InitTypeDef GPIO_InitStructure;
    GPIO_StructInit (&GPIO_InitStructure);

    GPIO_Init (port, &GPIO_InitStructure);
    uint32_t mask = portToMask (port);
    if (mask == 0)
        return;

    RCC_PB2PeriphClockCmd (mask, DISABLE);
}

uint8_t isPortEnabled (GPIO_TypeDef *port) {
    uint32_t mask = portToMask (port);
    if (mask == 0)
        return DISABLE;

    if ((RCC->PB2PCENR & mask) > 0)
        return ENABLE;

    return DISABLE;
}

void pinModeFast (GPIO_TypeDef *port, uint16_t pins, GPIOMode_TypeDef mode) {
    GPIO_InitTypeDef GPIO_InitStructure = {
        .GPIO_Pin = pins,
        .GPIO_Speed = GPIO_Speed_30MHz,
        .GPIO_Mode = mode};

    uint32_t mask = portToMask (port);
    if (mask == 0)
        return;

    RCC_PB2PeriphClockCmd (mask, ENABLE);
    GPIO_Init (port, &GPIO_InitStructure);
}

uint16_t pinToDigitalPin (uint8_t gpio_pin) {
    if (gpio_pin == 0 || gpio_pin > sizeof (_pin_map)) {
        printf ("\nError: Некоректний номер піна: %u", gpio_pin);
        return INVALID_MAPPING;
    }

    u16 pin = _pin_map[gpio_pin - 1].pin;

    if (pin == INVALID_MAPPING)
        printf ("\nError: Не GPIO пін: %u", gpio_pin);

    return pin;
}

GPIO_TypeDef *pinToPort (uint8_t gpio_pin) {
    if (gpio_pin == 0 || gpio_pin > sizeof (_pin_map)) {
        printf ("\nError: Некоректний номер піна: %u", gpio_pin);
        return NULL;
    }

    GPIO_TypeDef *port = _pin_map[gpio_pin - 1].port;

    if (port == NULL)
        printf ("\nError: Не GPIO пін: %u", gpio_pin);

    return port;
}

uint16_t pinToAdcChann (uint8_t gpio_pin) {
    if (gpio_pin == 0 || gpio_pin > sizeof (_pin_map)) {
        printf ("\nError: Некоректний номер піна: %u", gpio_pin);
        return ADC_CHANN_NONE;
    }

    u8 adc_chann = _pin_map[gpio_pin - 1].adc_chann;

    if (adc_chann == ADC_CHANN_NONE)
        printf ("\nError: Пін не має ADC-каналу: %u", gpio_pin);
    
    return adc_chann;
}

void pinMode (uint8_t gpio_pin, GPIOMode_TypeDef mode) {
    if (mode == GPIO_Mode_AIN) {
        u8 adc_chann = pinToAdcChann (gpio_pin);

        if (adc_chann == ADC_CHANN_NONE)
            return;
    }

    u16 pin = pinToDigitalPin (gpio_pin);
    if (pin == INVALID_MAPPING)
        return;

    pinModeFast (_pin_map[gpio_pin - 1].port, pin, mode);
}

void digitalWrite (uint8_t gpio_pin, PinState state) {
    u16 pin = pinToDigitalPin (gpio_pin);
    if (pin == INVALID_MAPPING)
        return;

    GPIO_WriteBit (_pin_map[gpio_pin - 1].port, pin, (BitAction)state);
}

PinState digitalRead (uint8_t gpio_pin) {
    u16 pin = pinToDigitalPin (gpio_pin);
    if (pin == INVALID_MAPPING)
        return LOW;

    if (GPIO_ReadInputDataBit (_pin_map[gpio_pin - 1].port, pin) == Bit_RESET)
        return LOW;

    return HIGH;
}

void togglePin (uint8_t gpio_pin) {
    u16 pin = pinToDigitalPin (gpio_pin);
    if (pin == INVALID_MAPPING)
        return;

    u8 val = GPIO_ReadOutputDataBit (_pin_map[gpio_pin - 1].port, pin);
    val = !val;

    GPIO_WriteBit (_pin_map[gpio_pin - 1].port, pin, val);
}

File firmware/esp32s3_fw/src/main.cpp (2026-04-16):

#include "context/resources/ch32_pins_def.h"
#include "pixeler/setup/input_setup.h"
#include "pixeler/src/Pixeler.h"
#include "pixeler/src/manager/CoprocessorManager.h"
using namespace pixeler;

void setup()
{
  // Перевірити з'єднання з допоміжним МК.
  if (!pixeler::_ccpu.connect())
    esp_restart();

  // Увімкнути живлення дисплея з допоміжного МК.
  uint8_t ccpu_cmd_data[2]{CCPU_CMD_PIN_ON, CH_PIN_DISPLAY_PWR};
  _ccpu.sendCmd(ccpu_cmd_data, sizeof(ccpu_cmd_data));

  // Увімкнути всі кнопки на допоміжному МК.
  ccpu_cmd_data[0] = CCPU_CMD_BTN_ON;

  ccpu_cmd_data[1] = BtnID::BTN_OK;
  _ccpu.sendCmd(ccpu_cmd_data, sizeof(ccpu_cmd_data), 2);

  ccpu_cmd_data[1] = BtnID::BTN_BACK;
  _ccpu.sendCmd(ccpu_cmd_data, sizeof(ccpu_cmd_data), 2);

  ccpu_cmd_data[1] = BtnID::BTN_LEFT;
  _ccpu.sendCmd(ccpu_cmd_data, sizeof(ccpu_cmd_data), 2);

  ccpu_cmd_data[1] = BtnID::BTN_RIGHT;
  _ccpu.sendCmd(ccpu_cmd_data, sizeof(ccpu_cmd_data), 2);

  ccpu_cmd_data[1] = BtnID::BTN_UP;
  _ccpu.sendCmd(ccpu_cmd_data, sizeof(ccpu_cmd_data), 2);

  ccpu_cmd_data[1] = BtnID::BTN_DOWN;
  _ccpu.sendCmd(ccpu_cmd_data, sizeof(ccpu_cmd_data), 2);

  // Вимкнути всю периферію на допоміжному МК.
  ccpu_cmd_data[0] = CCPU_CMD_PIN_OFF;

  ccpu_cmd_data[1] = CH_PIN_MIC_PWR;
  _ccpu.sendCmd(ccpu_cmd_data, sizeof(ccpu_cmd_data), 2);

  ccpu_cmd_data[1] = CH_PIN_LORA_PWR;
  _ccpu.sendCmd(ccpu_cmd_data, sizeof(ccpu_cmd_data), 2);

  ccpu_cmd_data[1] = CH_PIN_SPK_PWR;
  _ccpu.sendCmd(ccpu_cmd_data, sizeof(ccpu_cmd_data));

  // Запустити виконання Pixeler.
  Pixeler::begin(80);
}

void loop()
{
  vTaskDelete(NULL);
}

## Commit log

2025-07-09 Додано проєкт плати
    [perfect_console.kicad_pcb, perfect_console.kicad_sch]
2025-07-09 Виправлено позицію піна на платі
    [perfect_console.kicad_pcb]
2025-07-10 Допрацювання плати
    [perfect_console.kicad_pcb, perfect_console.kicad_sch]
2025-07-10 Допрацювання схеми
    [perfect_console.kicad_pcb, perfect_console.kicad_sch]
2025-07-10 Покращення схеми
    [perfect_console.kicad_pcb, perfect_console.kicad_sch]
2025-07-10 Додано каркас для прошивки з тестами заліза
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2025-07-11 Доопрацювання схеми
    [perfect_console.kicad_pcb, perfect_console.kicad_sch]
2025-07-11 Додано тести для аудіо
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2025-07-16 Виправлення посадкових місць
    [perfect_console.kicad_pcb]
2025-07-18 Корегування схеми
    [perfect_console.kicad_pcb]
2025-07-20 Виправлено перехід в сон
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2025-07-22 Виправлено символ
    [perfect_console.kicad_pcb, perfect_console.kicad_sch]
2025-07-22 Виправлено імена міток
    [perfect_console.kicad_pcb, perfect_console.kicad_sch]
2025-07-23 Додано визначення додаткових пінів
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2025-07-23 Перепрацьовано схему
    Карту пам'яті і дисплей рознесено на окремі шини
    [perfect_console.kicad_pcb, perfect_console.kicad_sch]
2025-07-28 Виправлено схему
    [perfect_console.kicad_pcb]
2025-08-02 Виправлено печатну плату
    [perfect_console.kicad_pcb]
2025-08-02 Додано зображення для ЛУТ
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2025-08-02 Виправлено імена елементів перечислення
2025-08-02 SD_CS пін перенесено на 10 пін ESP32S3
    [perfect_console.kicad_pcb, perfect_console.kicad_sch]
2025-08-02 Тести будуть перенесені в основну прошивку
2025-08-03 Додано контекст файлового менеджера
2025-08-08 Виправлено зону потенційного КЗ
    [perfect_console.kicad_pcb]
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2025-08-13 Додано адаптовані контексти
    [30.csv, 31.csv, 32.csv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]
2025-08-16 Додано налаштування для налагодження
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2025-08-16 Додано нагадування про можливий збій UART
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2025-08-17 Додано зчитування заряду акума
2025-08-17 Додано заготовку контексту рації
2025-08-18 Додано фільтруючий конденсатор на VVAL
    [perfect_console.kicad_pcb, perfect_console.kicad_sch]
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2025-08-18 Переміщено іконку в загальні ресурси
2025-08-19 Відокремлено зчитування заряду акумулятора
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2025-08-25 Виправлено роботу з глобальними об'єктами
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2025-08-27 Переписано структуру контексту рації
2025-08-27 Розділено на проєкти для ЛУТ та заводу
    [perfect_console.kicad_pcb, perfect_console.kicad_sch]
2025-09-01 Реалізовано збереження і завантаження налаштувань кодеку
2025-09-02 Реалізовано додаткові можливості
    Реалізовано: запуск тесту кодування-декодування аудіо, налаштування чергування даних мікрофону та підсилення звуку.
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2025-09-06 Додано заготовки відповідних контекстів
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2025-09-08 Додано скидання пінів периферії
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2025-09-19 Покращення PCB
    [perfect_console.kicad_pcb, perfect_console.kicad_sch]
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2025-09-20 Видалено ESD мікросхему та її конденсатор
    [perfect_console.kicad_pcb, perfect_console.kicad_sch]
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2025-09-22 Змінено на більший шрифт контекстного меню
2025-09-22 Додано обмін налаштуваннями рації
2025-09-22 Виправлено помилку обробки кінця плейлиста
2025-09-23 Змінено рівень виводу логів
2025-09-23 Додано відсутню ініціалізацію фільтрів
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2025-09-23 Перевірка функціонування рації в loop
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2025-09-26 Змінено порядок пунктів меню
2025-09-27 Переміщено у відповідний каталог
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2025-09-30 Видалено резервні копії старих файлів
2025-09-30 Додано підтримку lua в файловий менеджер
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2025-10-02 Додано інструкцію прошивки CH32V006E8R6
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2025-10-02 Додано інструкцію з прошивки ESP32S3
2025-10-02 Додано рекомендації до процесу збірки плати
2025-10-03 Виправлено ім'я константного рядка
2025-10-03 Додано встановлення шпалер з файлового менеджера
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2025-10-04 Виправлено некоректний запис налаштувань
2025-10-04 Додано зображення шпалер для 240x320
2025-10-04 Зменшено розмір індикатора заряду акумулятора
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2025-10-15 Портування на Pixeler
    [partitions-s3.csv]
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2025-10-17 Видалено зайві виклики методів
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2025-10-26 Виправлено помилки відображення тексту
    Виправлено помилки підрахунку ширини тексту з деякими символами
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2025-11-03 Портовано ігровий рушій
    [30.csv, 31.csv, 32.csv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]
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2025-11-15 Додано автоматичний завантажувач ресурсів поверхні
    Додано автоматичний завантажувач ресурсів поверхні сцени з диску.
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2025-11-15 Видалено непотрібний параметр
    Менеджер ресурсів вже оголошено глобально
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2025-12-16 Переміщено в окремий репо
    [30.csv, 31.csv, 32.csv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]
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2026-01-16 Додано приклад керування wifi та запитів до web
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2026-02-22 Додано маркування мосфетів
    [perfect_console.kicad_sch]
2026-02-22 Зменшено розміри плати
    [perfect_console.kicad_pcb]
2026-02-22 Видалено креслення для ручного виготовлення
    [perfect_console.kicad_pcb, perfect_console.kicad_sch]
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2026-03-22 Додано таблицю розділів для esp32
    [partitions.csv]
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2026-03-28 fix: віджети не компілювалися з вимкнутою графікою
2026-03-28 fix: Методи для взаємодії з графікою доступні без неї
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2026-03-31 Додано таблицю розділів для ESP32P4
    [partitions-p4.csv]
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2026-04-12 fix: Відсутнє оновлення після зміни типу поля
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2026-04-13 fix: Некоректно встановлюється курсор
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2026-04-15 Приклади видалено на доопрацювання
    [cave.csv, main_map.csv]
2026-04-15 Оновлено архітектуру ігрового рушія
    Методи взаємодії з поверхнею ігрового рівня, створення та вибірки об'єктів, переміщено до класу ігрової сцени.
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
